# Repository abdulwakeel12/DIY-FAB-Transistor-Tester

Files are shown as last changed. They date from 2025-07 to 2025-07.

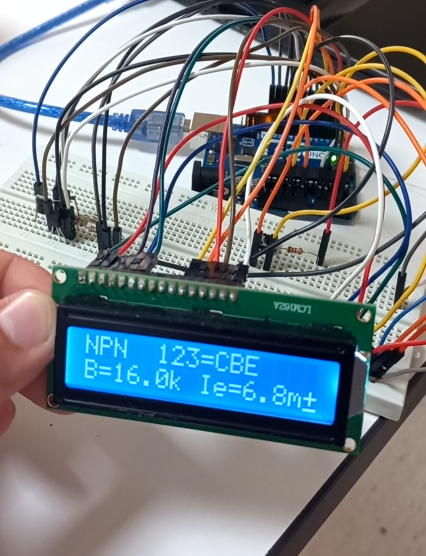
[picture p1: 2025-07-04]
images/Operating TT 2.jpg

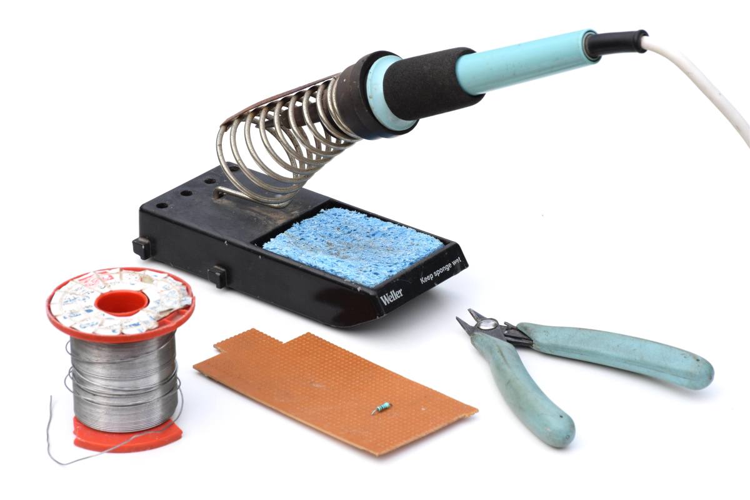
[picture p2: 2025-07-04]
images/Soldering.jpg

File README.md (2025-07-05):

# DIY FAB Transistor Tester

> **4th Semester Project**  
> **Duration:** March 2022 – July 2022  
> **Institution:** Sukkur IBA University  
> **Department:** Electrical Engineering  
> **Course:** Introduction to Embedded System  
> **Supervisor:** Dr. Muhammad Asim Samejo   

---

## 👥 Group Members

- Wakeel Ahmed (CMS ID: 033-19-0026)  
- Bhai Khan (CMS ID: 033-19-0015)

---

## 📌 Project Description

This DIY FAB Transistor Tester is a compact device designed to identify and measure various electronic components. It uses an ATmega328P-based Arduino UNO to test and display data such as pin configuration, polarity, and key parameters on a 16x2 LCD screen.

It supports automatic identification of:
- Bipolar Junction Transistors (NPN, PNP)
- MOSFETs (N-Channel, P-Channel)
- JFETs, IGBTs, Thyristors, and Triacs
- Diodes and Zener Diodes
- Capacitors and Resistors

---

## 🧰 Technologies & Tools Used

- **Arduino UNO (ATmega328P)**
- **Eagle PCB Design Software**
- **Ultimaker 3D Printer**
- **Cura Slicer for 3D Printing**
- **HTML, CSS** (for project documentation)
- **Fritzing** (for high-level schematic design)
- **FTDI, ICSP Bootloader Programming**
- **16x2 LCD Display**

---

## 💡 Features

- Auto-detection of transistor type, pins, and characteristics
- Displays:
  - Gain (hFE), V<sub>BE</sub>
  - R<sub>DS(on)</sub> for MOSFETs
  - Capacitance and resistance
- Menu selection & self-test modes
- USB-powered via Mini USB port
- Fully enclosed in a 3D-printed custom case

---

## 📷 Project Gallery

project/
│
├── index.html # Project report
├── style.css # Styling
├── images/ # Photos, schematics, designs...

---

## 💰 Bill of Materials

| Component | Cost (PKR) |
|---|---|
| Full PCB | Rs. 1,500 |
| LCD Display | Rs. 488 |
| 3D Printing (Plastic) | Rs. 2,500 |
| Steel Rod | Rs. 600 |
| **Total** | **Rs. 5,088** |

---

## 🔗 Project Resources

- 🔗 [**Reference Guide**](https://create.arduino.cc/projecthub/plouc68000/ardutester-v1-13-the-arduino-uno-transistor-tester-dbafb4)
- 💻 [**Source Code (Arduino)**](https://create.arduino.cc/editor/plouc68000/d6b548e6-37af-4cf0-b95f-cbaa9e89ea72/preview)
- 📐 [**CAD STL File**](https://github.com/wagiminator/ATmega-Transistor-Tester/blob/master/hardware/TransistorTester_case.stl)
- 🧩 [**Fritzing Circuit File**](https://fritzing.org/projects/tester)

---

## 📽️ Demonstration Videos

- [<a href="https://www.youtube.com/embed/zdPWsUJlSmU" target="_blank">📺 Breadboard Prototype & Bootloading</a>
- [<a href="https://www.youtube.com/embed/i-WZqEvgACc" target="_blank">📺 Final Circuit Operation</a>

---

## 💼 Business Objective

To design a low-cost, portable, and easy-to-use transistor tester that provides more detail than standard multimeters — including automatic schematic recognition, polarity, and gain factor measurement — making it ideal for academic labs and DIY engineers.

---

## 🧑‍🏫 Supervision

**Dr. Muhammad Asim Samejo**  
Department of Electrical Engineering  
Sukkur IBA University

---

## 🧑‍💻 Developed By

- **Wakeel Ahmed** (033-19-0026)  
- **Bhai Khan** (033-19-0015)

---

## 📜 License

This project is intended for educational purposes.  
© 2022 Bhai Khan & Wakeel Ahmed — All rights reserved.

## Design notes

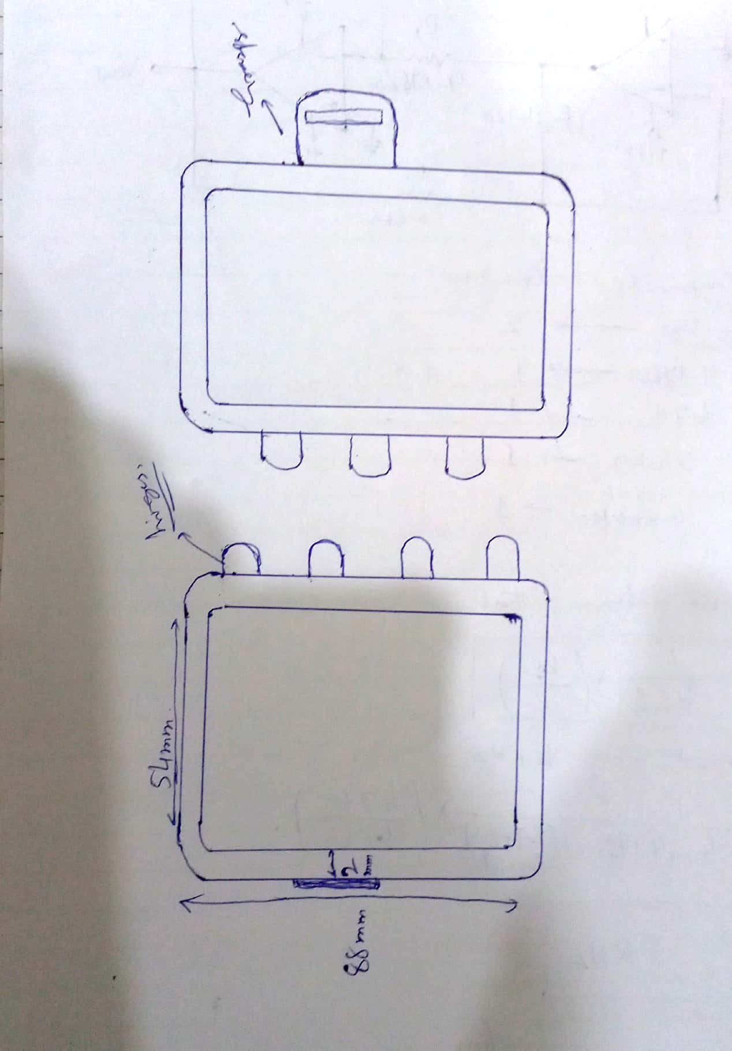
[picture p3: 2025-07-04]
images/Roughly Mechanical Sketch.jpg

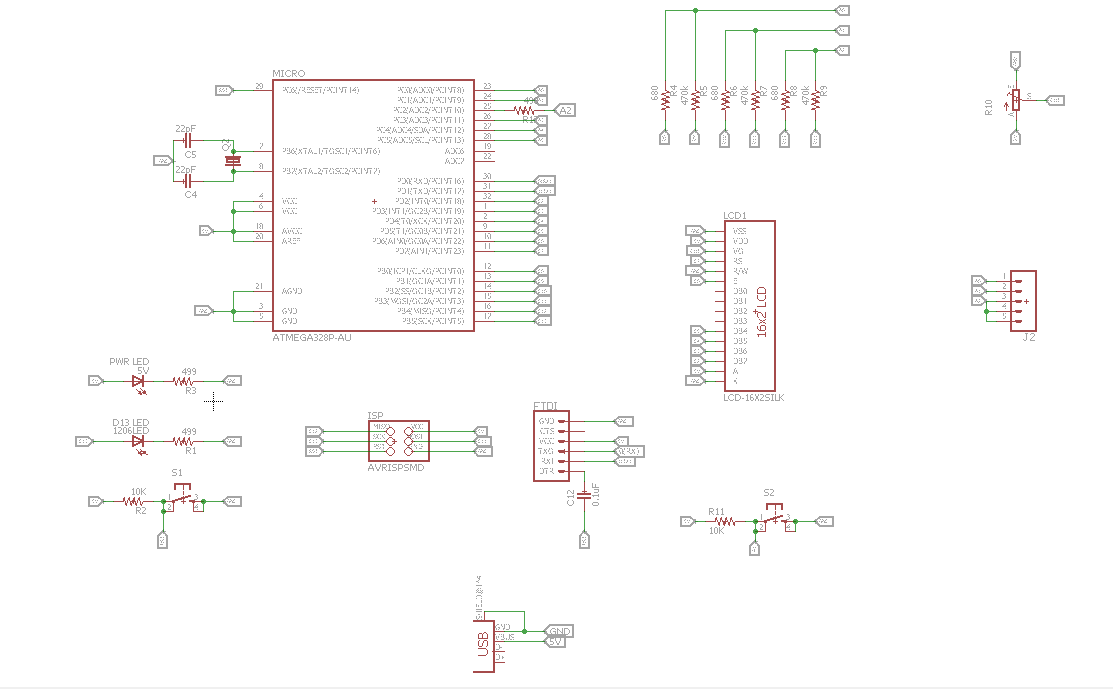
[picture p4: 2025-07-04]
images/Electrical Schematic.jpg

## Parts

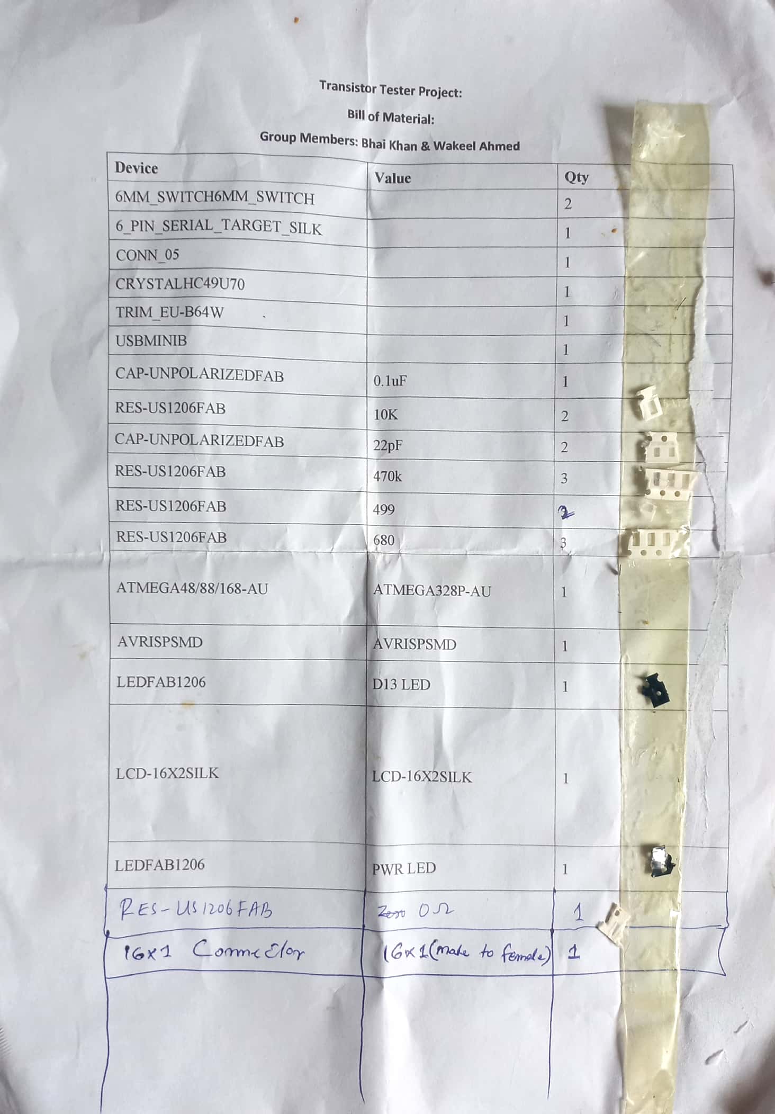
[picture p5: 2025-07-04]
images/Bill Of Material.jpg

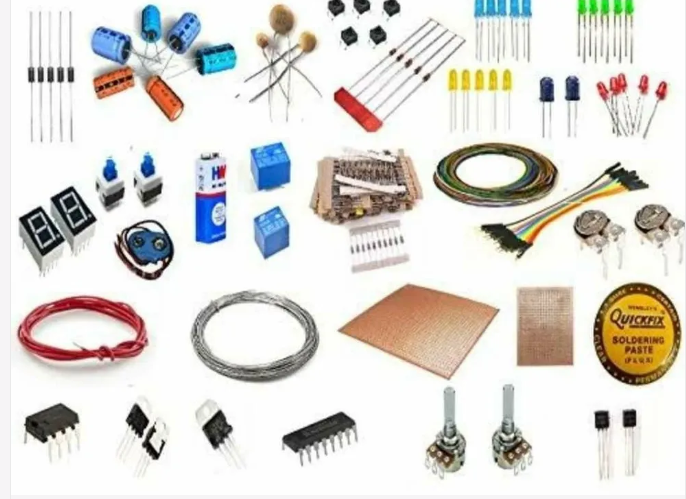
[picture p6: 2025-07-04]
images/Selection of components.jpg

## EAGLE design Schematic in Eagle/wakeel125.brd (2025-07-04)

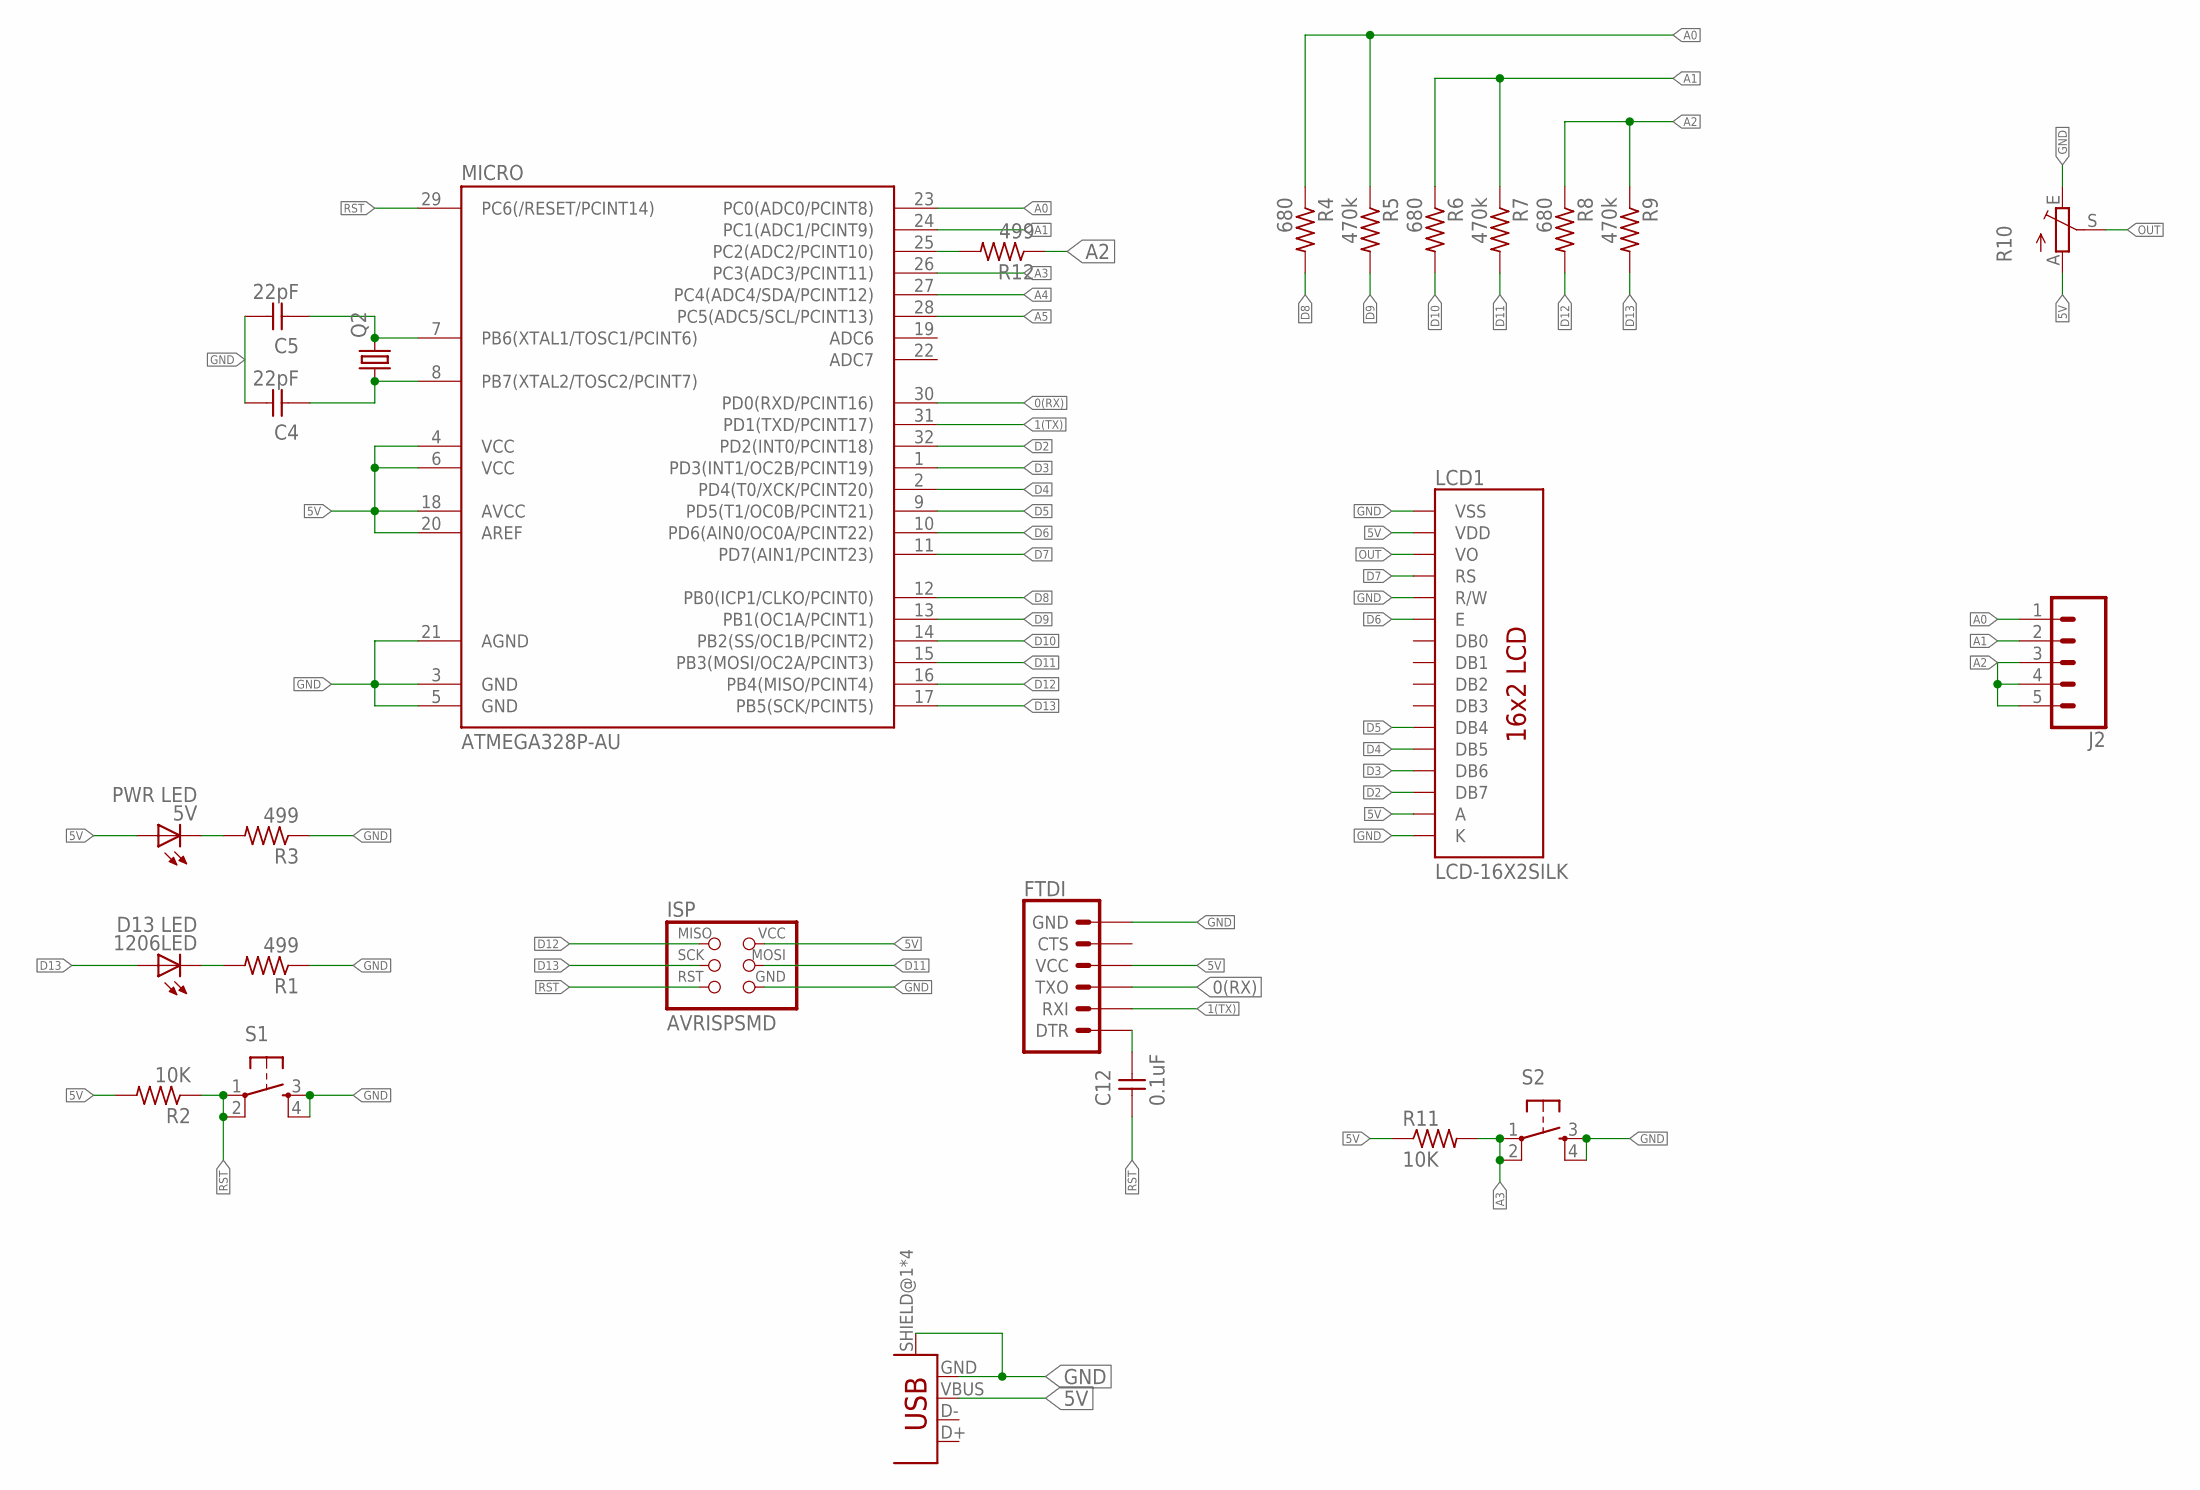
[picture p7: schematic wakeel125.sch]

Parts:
5V: PWR LED; LED1206FAB
1206LED: D13 LED; LED1206FAB
C4, C5: 22pF; C1206FAB
C12: 0.1uF; C1206FAB
CN1: USB_MINIB
FTDI: 6_PIN_SERIAL_TARGET_SILK; 1X06
ISP: AVRISPSMD; 2X03SMD
J2: CONN_05; 1X05
LCD1: LCD-16X2SILK; LCD-16X2
MICRO: ATMEGA328P-AU; TQFP32-08
Q2: CRYSTALHC49U70; HC49U70
R1, R3, R12: 499; R1206FAB
R2, R11: 10K; R1206FAB
R4, R6, R8: 680; R1206FAB
R5, R7, R9: 470k; R1206FAB
R10: TRIM_EU-B64W; B64W
S1, S2: 6MM_SWITCH6MM_SWITCH; 6MM_SWITCH

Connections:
0(RX): FTDI.3 (TXO), MICRO.30 (PD0(RXD/PCINT16))
1(TX): FTDI.2 (RXI), MICRO.31 (PD1(TXD/PCINT17))
5V: 5V.1 (A), CN1.VBUS, FTDI.4 (VCC), ISP.2 (VCC), LCD1.2 (VDD), LCD1.15 (A), MICRO.4 (VCC), MICRO.6 (VCC), MICRO.18 (AVCC), MICRO.20 (AREF), R2.2, R10.A, R11.1
A0: J2.1, MICRO.23 (PC0(ADC0/PCINT8)), R4.1, R5.1
A1: J2.2, MICRO.24 (PC1(ADC1/PCINT9)), R6.1, R7.1
A2: J2.3, J2.4, J2.5, R8.1, R9.1, R12.1
A3: MICRO.26 (PC3(ADC3/PCINT11)), R11.2, S2.1, S2.2 (P1)
A4: MICRO.27 (PC4(ADC4/SDA/PCINT12))
A5: MICRO.28 (PC5(ADC5/SCL/PCINT13))
D2: LCD1.14 (DB7), MICRO.32 (PD2(INT0/PCINT18))
D3: LCD1.13 (DB6), MICRO.1 (PD3(INT1/OC2B/PCINT19))
D4: LCD1.12 (DB5), MICRO.2 (PD4(T0/XCK/PCINT20))
D5: LCD1.11 (DB4), MICRO.9 (PD5(T1/OC0B/PCINT21))
D6: LCD1.6 (E), MICRO.10 (PD6(AIN0/OC0A/PCINT22))
D7: LCD1.4 (RS), MICRO.11 (PD7(AIN1/PCINT23))
D8: MICRO.12 (PB0(ICP1/CLKO/PCINT0)), R4.2
D9: MICRO.13 (PB1(OC1A/PCINT1)), R5.2
D10: MICRO.14 (PB2(SS/OC1B/PCINT2)), R6.2
D11: ISP.4 (MOSI), MICRO.15 (PB3(MOSI/OC2A/PCINT3)), R7.2
D12: ISP.1 (MISO), MICRO.16 (PB4(MISO/PCINT4)), R8.2
D13: 1206LED.1 (A), ISP.3 (SCK), MICRO.17 (PB5(SCK/PCINT5)), R9.2
GND: C4.2, C5.2, CN1.GND, CN1.SHIELD@1 (SHIELD), CN1.SHIELD@2 (SHIELD), CN1.SHIELD@3 (SHIELD), CN1.SHIELD@4 (SHIELD), FTDI.6 (GND), ISP.6 (GND), LCD1.1 (VSS), LCD1.5 (R/W), LCD1.16 (K), MICRO.3 (GND), MICRO.5 (GND), MICRO.21 (AGND), R1.1, R3.1, R10.E, S1.3 (S), S1.4 (S1), S2.3 (S), S2.4 (S1)
unnamed: 1206LED.2 (C), R1.2
unnamed: 5V.2 (C), R3.2
unnamed: C5.1, MICRO.7 (PB6(XTAL1/TOSC1/PCINT6)), Q2.2
unnamed: C4.1, MICRO.8 (PB7(XTAL2/TOSC2/PCINT7)), Q2.1
unnamed: MICRO.25 (PC2(ADC2/PCINT10)), R12.2
unnamed: C12.2, FTDI.1 (DTR)
OUT: LCD1.3 (VO), R10.S
RST: C12.1, ISP.5 (RST), MICRO.29 (PC6(/RESET/PCINT14)), R2.1, S1.1, S1.2 (P1)

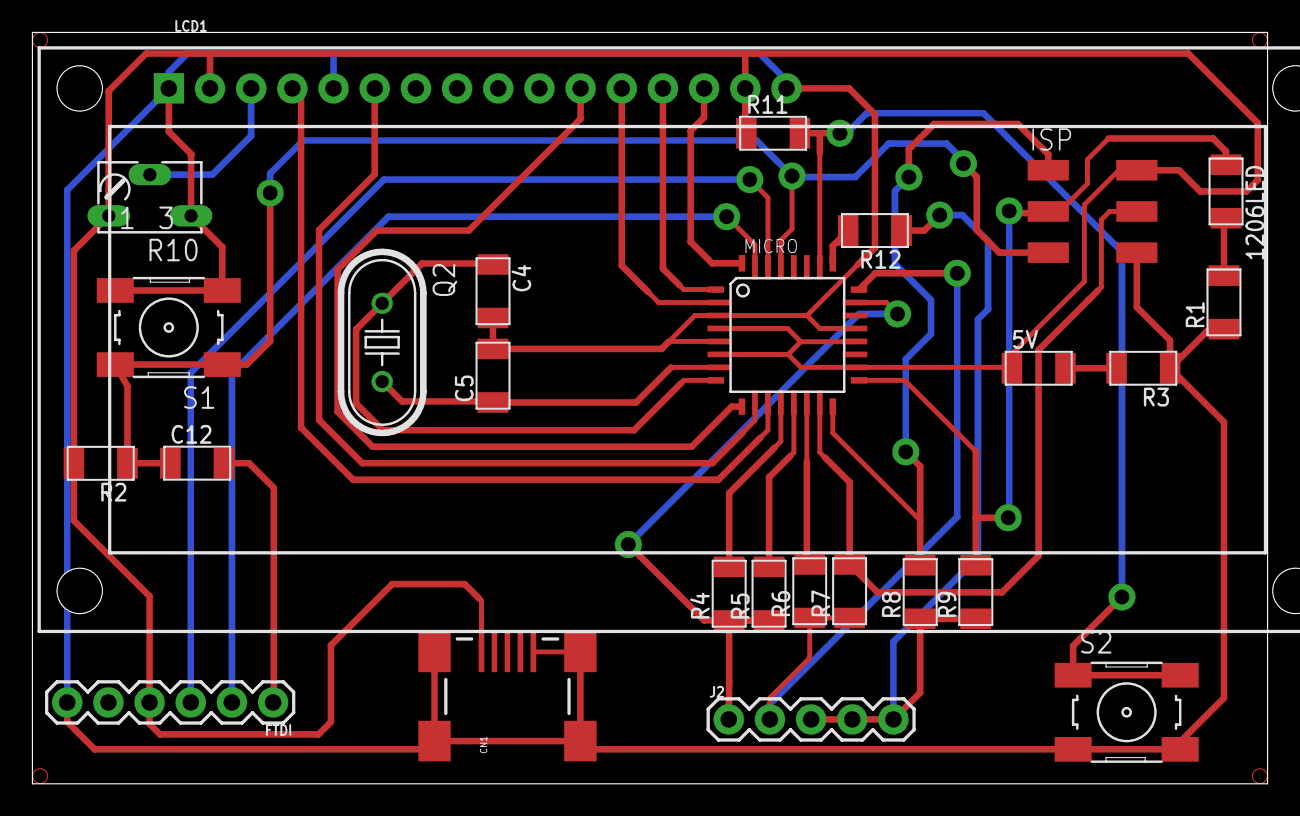
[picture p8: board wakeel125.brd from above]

Board: 2 copper layers, 76.2 x 46.4 mm, 26 parts (0 on the bottom side), 28 nets.

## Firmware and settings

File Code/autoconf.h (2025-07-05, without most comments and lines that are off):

#if ((LCD_ST_TYPE == 7565) || (LCD_ST_TYPE == 1306) || (LCD_ST_TYPE == 7108) || (LCD_ST_TYPE == 7920) || (LCD_ST_TYPE == 7735) || (LCD_ST_TYPE == 9163) || (LCD_ST_TYPE == 9341) || (LCD_ST_TYPE == 1327))
 #if ((SCREEN_HEIGHT > 128) && (SCREEN_WIDTH > 255))
  #define ONE_B 16
 #else
  #define ONE_B 8
 #endif
 #define WITH_GRAPHICS 1
 #undef PAGES_PER_LINE
 #define PAGES_PER_LINE ((FONT_HEIGHT + 7) / 8)
 #undef LCD_LINES
 #define LCD_LINES ((SCREEN_HEIGHT/ONE_B) / PAGES_PER_LINE)
 #undef LCD_LINE_LENGTH
 #define LCD_LINE_LENGTH (SCREEN_WIDTH / (ONE_B/8) / FONT_WIDTH )
 #define TEXT_RIGHT_TO_ICON ((ICON_WIDTH + 16 + 5 + 7) / FONT_WIDTH)
#elif (LCD_ST_TYPE == 8812)
 #define ONE_B 8
 #define WITH_GRAPHICS 1
 #undef PAGES_PER_LINE
 #define PAGES_PER_LINE ((FONT_HEIGHT + 7) / 8)
 #undef LCD_LINES
 #define LCD_LINES ((SCREEN_HEIGHT/8) / PAGES_PER_LINE)
 #undef LCD_LINE_LENGTH
 #define LCD_LINE_LENGTH (SCREEN_WIDTH / FONT_WIDTH)
 #define TEXT_RIGHT_TO_ICON ((ICON_WIDTH + 16 + 5 + 7) / FONT_WIDTH)
#elif (LCD_ST_TYPE == 8814)
 #define ONE_B 8
 #define WITH_GRAPHICS 1
 #undef PAGES_PER_LINE
 #define PAGES_PER_LINE ((FONT_HEIGHT + 7) / 8)
 #undef LCD_LINES
 #define LCD_LINES ((SCREEN_HEIGHT/8) / PAGES_PER_LINE)
 #undef LCD_LINE_LENGTH
 #define LCD_LINE_LENGTH (SCREEN_WIDTH / FONT_WIDTH)
 #define TEXT_RIGHT_TO_ICON ((ICON_WIDTH + 16 + 5 + 7) / FONT_WIDTH)
#else
 #define TEXT_RIGHT_TO_ICON 0
  #define FONT_HEIGHT 8
#endif
 #define LCD_ST7565_H_OFFSET 0
 #define LCD_ST7565_Y_START  0
#if LCD_ST7565_Y_START >= SCREEN_HEIGHT
 #warning LCD_ST7565_Y_START is set higher than SCREEN_HEIGHT!
#endif
#ifndef LCD_LINE_LENGTH
 #define LCD_LINE_LENGTH 16
#endif
#if (defined(WITH_GRAPHICS) && (((SCREEN_WIDTH-(TEXT_RIGHT_TO_ICON*FONT_WIDTH))/FONT_WIDTH) < 9))
 #define LOW_H_SPACE 1
#else
 #define LOW_H_SPACE 0
#endif
#if (LCD_ST_TYPE != 7920)
#define lcd_refresh()
#endif
#if (LCD_LINES < 2)
 #warning LCD_LINES is not correctly set!
 #if (SCREEN_HEIGHT < 32)
  #warning SCREEN_HEIGHT is not correctly set!
 #endif
 #if (FONT_HEIGHT < 8)
  #warning FONT_HEIGHT is not correctly set!
 #endif
#endif
#if (LCD_LINES < 7) && defined(WITH_6_SELECTION_MENU)
 #warning Display has not sufficient count of lines for WITH_6_SELECTION_MENU !
 #undef WITH_6_SELECTION_MENU
#endif
#if (PROCESSOR_TYP == 8) || (PROCESSOR_TYP == 168) || (PROCESSOR_TYP == 328)
 #if FLASHEND > 0x1fff
  #ifdef TQFP_ADC6
    #undef TPext
    #define TPext ((1<<MUX2) | (1<<MUX1))
    #ifdef TQFP_ADC7
      #define TPex2 ((1<<MUX2) | (1<<MUX1) | (1<<MUX0))
    #endif
  #else
    #ifdef TQFP_ADC7
      #undef TPext
      #define TPext ((1<<MUX2) | (1<<MUX1) | (1<<MUX0))
    #else
     #if (WITH_UART != 0) && (WITH_VEXT != 0)
      #warning "WITH_VEXT deselected, PC3 is used for UART"
      #undef WITH_VEXT
     #endif
    #endif
  #endif
 #else
  #ifndef BAT_CHECK
    #ifdef TQFP_ADC6
      #undef TPext
      #define TPext ((1<<MUX2) | (1<<MUX1))
    #endif
    #ifdef TQFP_ADC7
      #undef TPext
      #define TPext ((1<<MUX2) | (1<<MUX1) | (1<<MUX0))
    #endif
    #if (WITH_UART == 1) && (TQFP_ADC6 == 0) && (TQFP_ADC7 == 0) && (WITH_VEXT != 0)
      #warning "WITH_VEXT deselected, PC3 is used for UART"
      #undef WITH_VEXT
    #endif
  #endif
 #endif
#endif
#if BAT_NUMERATOR < BAT_DENOMINATOR
 #warning "Wrong BAT_NUMERATOR / BAT_DENOMINATOR setting!"
#endif
#if EXT_NUMERATOR < EXT_DENOMINATOR
 #warning "Wrong EXT_NUMERATOR / EXT_DENOMINATOR setting!"
#endif
  #define R_L_VAL 6800          // standard value 680 Ohm, multiplied by 10 for 0.1 Ohm resolution
  #define R_H_VAL 47000         // standard value 470000 Ohm, multiplied by 10, divided by 100
#if R_ANZ_MESS < ANZ_MESS
 #undef R_ANZ_MESS
 #define R_ANZ_MESS ANZ_MESS
#endif
#if U_SCALE < 1
 #undef U_SCALE
 #define U_SCALE 1
#endif
#if U_SCALE > 4
 #undef U_SCALE
 #define U_SCALE 4
#endif
 #define REF_L_KORR 50
#ifdef USE_EEPROM
 #define MEM_TEXT EEMEM
 #define lcd_MEM_string(a)  lcd_fix_string(a)
 #if E2END > 0X1FF
  #define MEM2_TEXT EEMEM
  #define MEM2_read_byte(a)  eeprom_read_byte(a)
  #define MEM2_read_word(a)  eeprom_read_word(a)
  #define lcd_MEM2_string(a)  lcd_fix_string(a)
  #define use_lcd_pgm
 #else
  #define MEM2_TEXT PROGMEM
  #define MEM2_read_byte(a)  pgm_read_byte(a)
  #define MEM2_read_word(a)  pgm_read_word(a)
  #define lcd_MEM2_string(a)  lcd_pgm_string(a)
  #define use_lcd_pgm
 #endif
 #define MEM_EEPROM
 #define MEM_read_word(a)  eeprom_read_word(a)
 #define MEM_read_byte(a)  eeprom_read_byte(a)
#else
 #define MEM_TEXT PROGMEM
 #define lcd_MEM_string(a)  lcd_pgm_string(a)
 #define MEM2_TEXT PROGMEM
 #define MEM_read_word(a)  pgm_read_word(a)
 #define MEM_read_byte(a)  pgm_read_byte(a)
 #define MEM2_read_byte(a)  pgm_read_byte(a)
 #define MEM2_read_word(a)  pgm_read_word(a)
 #define lcd_MEM2_string(a)  lcd_pgm_string(a)
 #define use_lcd_pgm
#endif
#if FLASHEND > 0X1FFF
 #define ACALL call
#else
 #define ACALL rcall
#endif
#if PROCESSOR_TYP == 168
  #define MCU_STATUS_REG MCUCR
  #define ADC_COMP_CONTROL ADCSRB
  #define TI1_INT_FLAGS TIFR1
  #define DEFAULT_BAND_GAP 1070
 #if R_H_VAL == 10000
  #define DEFAULT_RH_FAKT 4022      // mega168 1101 mV, 100.0 kOhm
 #else
  #define DEFAULT_RH_FAKT  856      // mega168 1101 mV, 470.0 kOhm
 #endif
  #define LONG_HFE
  #define PIN_RM 196
  #define PIN_RP 221
  #define CC0 36
  #define COMP_SLEW1 4000
  #define COMP_SLEW2 220
  #define C_NULL CC0+CABLE_CAP+(COMP_SLEW1 / (CC0 + CABLE_CAP + COMP_SLEW2))
  #define MUX_INT_REF 0x0e
#elif PROCESSOR_TYP == 328
  #define MCU_STATUS_REG MCUCR
  #define ADC_COMP_CONTROL ADCSRB
  #define TI1_INT_FLAGS TIFR1
  #define DEFAULT_BAND_GAP 1070
 #if R_H_VAL == 10000
  #define DEFAULT_RH_FAKT 4022      // mega328 1101 mV, 100.0 kOhm
 #else
  #define DEFAULT_RH_FAKT  856      // mega328 1101 mV, 470.0 kOhm
 #endif
  #define LONG_HFE
  #define PIN_RM 200
  #define PIN_RP 220
  #define CC0 36
  #define COMP_SLEW1 4000
  #define COMP_SLEW2 180
  #define C_NULL CC0+CABLE_CAP+(COMP_SLEW1 / (CC0 + CABLE_CAP + COMP_SLEW2))
  #define MUX_INT_REF 0x0e
#elif PROCESSOR_TYP == 644
  #define WITH_ROTARY_CHECK
  #define WITH_UJT
  #define WITH_PUT
  #define MCU_STATUS_REG MCUCR
  #define ADC_COMP_CONTROL ADCSRB
  #define TI1_INT_FLAGS TIFR1
  #define DEFAULT_BAND_GAP 1070
 #if R_H_VAL == 10000
  #define DEFAULT_RH_FAKT 4022      // mega1280 1101 mV, 100.0 kOhm
 #else
  #define DEFAULT_RH_FAKT  856      // mega1280 1101 mV, 470.0 kOhm
 #endif
  #define LONG_HFE
  #define PIN_RM 200
  #define PIN_RP 220
  #define CC0 36
  #define COMP_SLEW1 4000
  #define COMP_SLEW2 180
  #define C_NULL CC0+CABLE_CAP+(COMP_SLEW1 / (CC0 + CABLE_CAP + COMP_SLEW2))
  #define MUX_INT_REF 0x1e
#elif PROCESSOR_TYP == 1280
 #ifndef WITH_ROTARY_CHECK
  #define WITH_ROTARY_CHECK
 #endif
  #define MCU_STATUS_REG MCUCR
  #define ADC_COMP_CONTROL ADCSRB
  #define TI1_INT_FLAGS TIFR1
  #define DEFAULT_BAND_GAP 1070
 #if R_H_VAL == 10000
  #define DEFAULT_RH_FAKT 4022      // mega1280 1101 mV, 100.0 kOhm
 #else
  #define DEFAULT_RH_FAKT  856      // mega1280 1101 mV, 470.0 kOhm
 #endif
  #define LONG_HFE
  #define PIN_RM 200
  #define PIN_RP 220
  #define CC0 36
  #define COMP_SLEW1 4000
  #define COMP_SLEW2 180
  #define C_NULL CC0+CABLE_CAP+(COMP_SLEW1 / (CC0 + CABLE_CAP + COMP_SLEW2))
  #define MUX_INT_REF 0x1e
#else
  #define MCU_STATUS_REG MCUCSR
  #define ADC_COMP_CONTROL SFIOR
  #define TI1_INT_FLAGS TIFR
  #define DEFAULT_BAND_GAP 1298		//mega8 1298 mV
 #if R_H_VAL == 10000
  #define DEFAULT_RH_FAKT 3328      // mega8 1298 mV, 100.0 kOhm
 #else
  #define DEFAULT_RH_FAKT  740      // mega8 1250 mV, 470.0 kOhm
 #endif
  #define LONG_HFE
  #define PIN_RM 196
  #define PIN_RP 240
  #define CC0 27
  #define COMP_SLEW1 0
  #define COMP_SLEW2 33
  #define C_NULL CC0+CABLE_CAP+(COMP_SLEW1 / (CC0 + CABLE_CAP + COMP_SLEW2))
  #define MUX_INT_REF 0x0e
  #define INHIBIT_SLEEP_MODE
  #warning "SLEEP_MODE not possible with mega8"
#endif
 #define REF_R_KORR 0
 #define REF_C_KORR 0
#ifdef POWER_OFF
 #if (POWER_OFF+0) > 2
  #define OFF_WAIT_TIME SHORT_WAIT_TIME
 #else
  #define OFF_WAIT_TIME (LONG_WAIT_TIME - 1)
 #endif
#else
 #define OFF_WAIT_TIME  (LONG_WAIT_TIME - 1)
#endif
#define F_ADC 200000
#if F_CPU/F_ADC <= 2
 #define TICS_PER_ADC_CLOCK 2
 #define AUTO_CLOCK_DIV ((0<<ADPS2) | (0<<ADPS1) | (1<<ADPS0))
#elif F_CPU/F_ADC <= 4
 #define TICS_PER_ADC_CLOCK 4
 #define AUTO_CLOCK_DIV ((0<<ADPS2) | (1<<ADPS1) | (0<<ADPS0))
#elif F_CPU/F_ADC <= 8
 #define TICS_PER_ADC_CLOCK 8
 #define AUTO_CLOCK_DIV ((0<<ADPS2) | (1<<ADPS1) | (1<<ADPS0))
#elif F_CPU/F_ADC <= 16
 #define TICS_PER_ADC_CLOCK 16
 #define AUTO_CLOCK_DIV ((1<<ADPS2) | (0<<ADPS1) | (0<<ADPS0))
#elif F_CPU/F_ADC <= 32
 #define TICS_PER_ADC_CLOCK 32
 #define AUTO_CLOCK_DIV ((1<<ADPS2) | (0<<ADPS1) | (1<<ADPS0))
#elif F_CPU/F_ADC <= 64
 #define TICS_PER_ADC_CLOCK 64
 #define AUTO_CLOCK_DIV ((1<<ADPS2) | (1<<ADPS1) | (0<<ADPS0))
#else
 #define TICS_PER_ADC_CLOCK 128
 #define AUTO_CLOCK_DIV ((1<<ADPS2) | (1<<ADPS1) | (1<<ADPS0))
#endif
#ifndef PIN_RP
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

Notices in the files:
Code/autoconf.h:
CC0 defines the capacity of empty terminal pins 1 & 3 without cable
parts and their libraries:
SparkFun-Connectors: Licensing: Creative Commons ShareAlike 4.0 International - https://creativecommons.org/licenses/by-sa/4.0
